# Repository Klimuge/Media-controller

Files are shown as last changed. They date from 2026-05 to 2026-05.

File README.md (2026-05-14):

# MediaController

Компактный портативный медиаконтроллер на ESP32-S3 с механическими кнопками и Bluetooth.

## Что это
Устройство подключается к телефону или компьютеру по Bluetooth или type-c кабелю и управляет медиа:
следующий/предыдущий трек, пауза, громкость, выводит название трека, автора, сколько трека прошло,
сколько осталось или сколько он длится. Что выводится на экране и что делает четвёртая кнопка можно настроить

## Железо
- ESP32-S3-WROOM-1-N16R8
- Cherry MX Red — механические кнопки
- EC11 — энкодер для громкости
- LCD 2004 + I2C — дисплей
- LiPo 3.7В 3000мАч аккумулятор
- TP4056 — зарядка
- AP2112K-3.3 — LDO, питание логики 3.3V
- MTS-123 — тумблер переключения режимов

## Что сделано
- Схема и PCB в KiCad
- BOM с футпринтами
- 3д модели корпуса
- План кода

## Программная часть (не реализована)

Система состоит из трёх компонентов.

### Прошивка ESP32

NimBLE-Arduino (h2zero) — устройство представляется системе как BLE HID-клавиатура
и отправляет медиакейкоды. ESP32-S3 работает как составное USB-устройство одновременно:
HID (медиаклавиатура) + CDC (виртуальный COM-порт для агента).
ArduinoJson парсит входящие JSON-сообщения от агента и обновляет LCD.
Тумблер MTS-123 переключает режимы, состояние читается через GPIO38/GPIO39 с INPUT_PULLDOWN.
Энкодер EC11 управляет громкостью через прерывания.

### Агент

Фоновое приложение в системном трее. Читает метаданные текущего трека, системное время и т. д,
отправляет их на устройство по USB Serial (JSON). Если кабель не подключён то по Bluetooth. Также должен запускать программу
если пользователь настроит запуск программы на кастомную (четвёртую) кнопку

### PC-конфигуратор

GUI-приложение (PySide6). Пользователь настраивает устройство через интерфейс,
конфигуратор рендерит Jinja2-шаблон прошивки с этими настройками и автоматически
прошивает устройство через arduino-cli / esptool. Фактически — настройка и перепрошивка
без написания кода.

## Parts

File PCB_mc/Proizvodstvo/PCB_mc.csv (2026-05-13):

Идентиф. | Обозначение | Посад. место | Количество | Значение | Поставщик и справка
1 | SW6 | MTS | 1 | MTS-123
2 | U3 | SOIC-8-1EP_3.9x4.9mm_P1.27mm_EP2.41x3.3mm_ThermalVias | 1 | TP4056-42-ESOP8
3 | U1 | ESP32-S3-WROOM-1 | 1 | ESP32-S3-WROOM-1
4 | SW5 | RotaryEncoder_Alps_EC11E-Switch_Vertical_H20mm_MountingHoles | 1 | RotaryEncoder_Switch_EC11
5 | SW4,SW3,SW2,SW1 | SW_Cherry_MX_1.00u_PCB | 4 | Cherry MX Red
6 | J1 | USB_C_Receptacle_GCT_USB4105-xx-A_16P_TopMnt_Horizontal | 1 | USB_C_Receptacle_USB2.0_14P
7 | C4,C5 | C_1206_3216Metric_Pad1.33x1.80mm_HandSolder | 2 | 1uF
8 | F1 | Fuse_1206_3216Metric_Pad1.42x1.75mm_HandSolder | 1 | 0.5А 13.2В
9 | C6,C7 | C_1206_3216Metric_Pad1.33x1.80mm_HandSolder | 2 | 10uF
10 | R8,R7 | R_1206_3216Metric_Pad1.30x1.75mm_HandSolder | 2 | 1k
11 | R6 | R_1206_3216Metric_Pad1.30x1.75mm_HandSolder | 1 | 1.2k
12 | SW7 | SW_PUSH-12mm_Wuerth-430476085716 | 1 | boot
13 | D2 | LED_1206_3216Metric_Pad1.42x1.75mm_HandSolder | 1 | Green
14 | R2,R1 | R_1206_3216Metric_Pad1.30x1.75mm_HandSolder | 2 | 5.1K
15 | R4,R5 | R_1206_3216Metric_Pad1.30x1.75mm_HandSolder | 2 | 10К
16 | SW8 | SW_PUSH-12mm_Wuerth-430476085716 | 1 | rst
17 | C2,C3 | C_1206_3216Metric_Pad1.33x1.80mm_HandSolder | 2 | 100nF
18 | D1 | LED_1206_3216Metric_Pad1.42x1.75mm_HandSolder | 1 | Red
19 | R3 | R_1206_3216Metric_Pad1.30x1.75mm_HandSolder | 1 | 0.4
20 | U2 | SOT-23-5 | 1 | AP2112K-3.3
21 | BT1 | AMASS_XT60-M_1x02_P7.20mm_Vertical | 1 | 3.7V 3Ah
22 | lcd1 | JST_XH_B4B-XH-A_1x04_P2.50mm_Vertical | 1 | 2004
23 | D3,D4 | D_SOD-123 | 2 | MBR0540

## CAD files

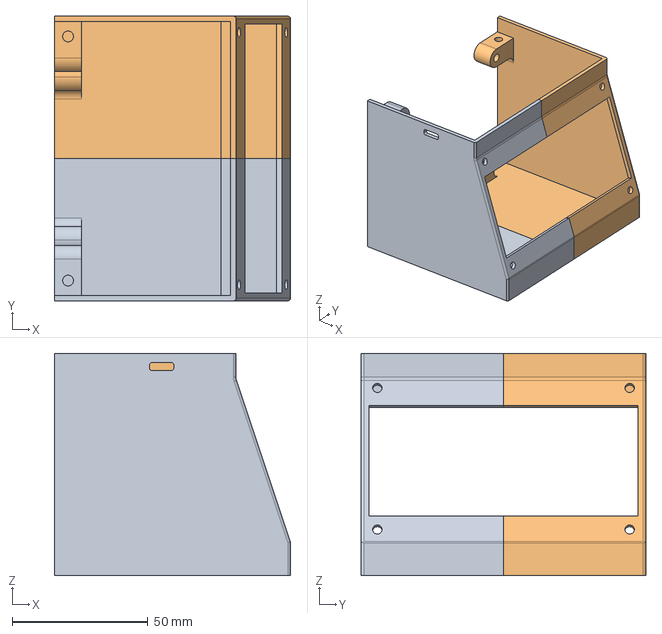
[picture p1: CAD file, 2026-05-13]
models/mc_base.step
87.0 x 105.0 x 82.0 mm

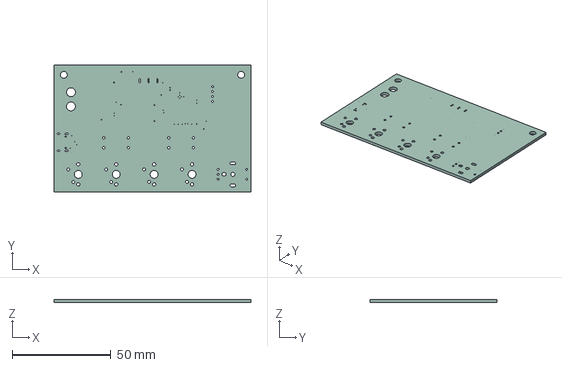
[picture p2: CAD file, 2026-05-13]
PCB_mc/PCB_mc.step
100.0 x 64.5 x 1.51 mm

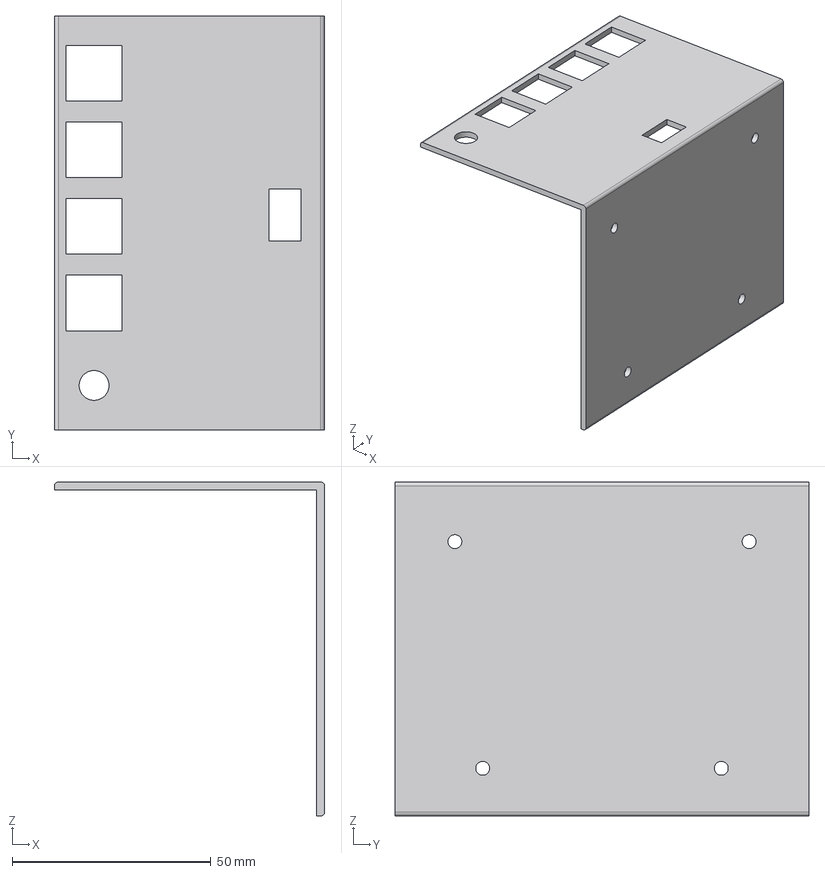
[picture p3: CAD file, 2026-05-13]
models/mc_cover.step
68.0 x 104.0 x 84.0 mm

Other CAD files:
models/mc_base.stl
models/mc_cover.stl

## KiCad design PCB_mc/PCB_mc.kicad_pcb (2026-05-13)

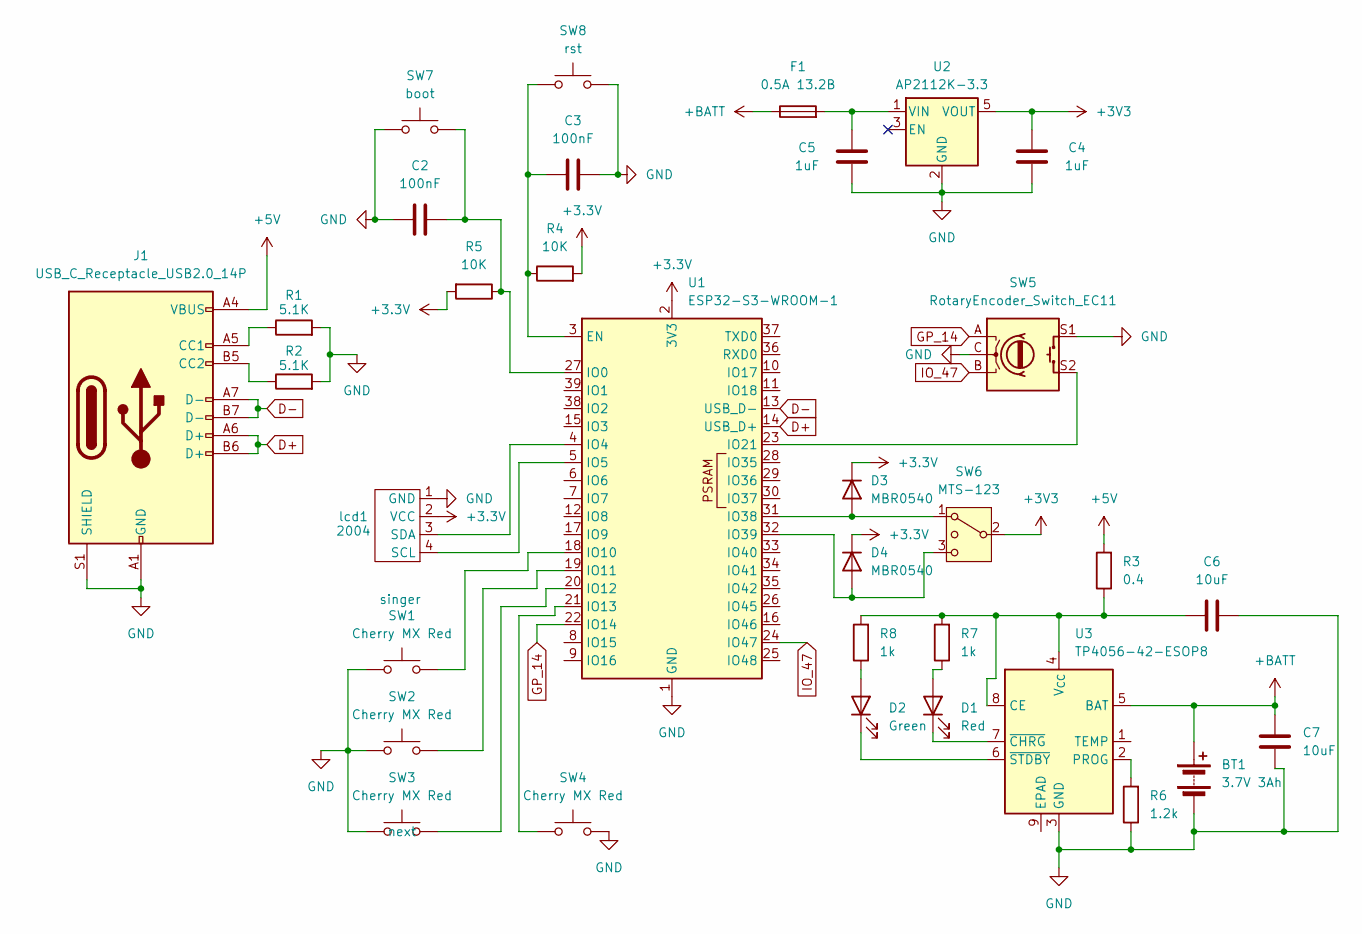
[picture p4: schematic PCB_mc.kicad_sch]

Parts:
BT1: 3.7V 3Ah; AMASS_XT60-M_1x02_P7.20mm_Vertical
C2, C3: 100nF; C_1206_3216Metric_Pad1.33x1.80mm_HandSolder
C4, C5: 1uF; C_1206_3216Metric_Pad1.33x1.80mm_HandSolder
C6, C7: 10uF; C_1206_3216Metric_Pad1.33x1.80mm_HandSolder
D1: Red; LED_1206_3216Metric_Pad1.42x1.75mm_HandSolder
D2: Green; LED_1206_3216Metric_Pad1.42x1.75mm_HandSolder
D3, D4: MBR0540; D_SOD-123
F1: 0.5А 13.2В; Fuse_1206_3216Metric_Pad1.42x1.75mm_HandSolder
J1: USB_C_Receptacle_USB2.0_14P; USB_C_Receptacle_GCT_USB4105-xx-A_16P_TopMnt_Horizontal
R1, R2: 5.1K; R_1206_3216Metric_Pad1.30x1.75mm_HandSolder
R3: 0.4; R_1206_3216Metric_Pad1.30x1.75mm_HandSolder
R4, R5: 10К; R_1206_3216Metric_Pad1.30x1.75mm_HandSolder
R6: 1.2k; R_1206_3216Metric_Pad1.30x1.75mm_HandSolder
R7, R8: 1k; R_1206_3216Metric_Pad1.30x1.75mm_HandSolder
SW1, SW2, SW3, SW4: Cherry MX Red; SW_Cherry_MX_1.00u_PCB
SW5: RotaryEncoder_Switch_EC11; RotaryEncoder_Alps_EC11E-Switch_Vertical_H20mm_MountingHoles
SW6: MTS-123; MTS
SW7: boot; SW_PUSH-12mm_Wuerth-430476085716
SW8: rst; SW_PUSH-12mm_Wuerth-430476085716
U1: ESP32-S3-WROOM-1
U2: AP2112K-3.3; SOT-23-5
U3: TP4056-42-ESOP8; SOIC-8-1EP_3.9x4.9mm_P1.27mm_EP2.41x3.3mm_ThermalVias
lcd1: 2004; JST_XH_B4B-XH-A_1x04_P2.50mm_Vertical

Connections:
+3.3V: D3.1 (K), D4.1 (K), R4.2, R5.2, U1.2 (3V3), lcd1.2 (VCC)
+3V3: C4.2, SW6.2 (3), U2.5 (VOUT)
+5V: J1.A4 (VBUS), J1.A9 (VBUS), J1.B4 (VBUS), J1.B9 (VBUS), R3.2
+BATT: BT1.1 (+), C7.1, F1.1, U3.5 (BAT)
D+: J1.A6 (D+), J1.B6 (D+), U1.14 (USB_D+)
D-: J1.A7 (D-), J1.B7 (D-), U1.13 (USB_D-)
GND: BT1.2 (-), C2.1, C3.1, C4.1, C5.1, C6.1, C7.2, J1.A1 (GND), J1.A12 (GND), J1.B1 (GND), J1.B12 (GND), J1.S1 (SHIELD), R1.2, R2.2, R6.1, SW1.1, SW2.1, SW3.1, SW4.2, SW5.C, SW5.S1, SW7.1, SW8.1, U1.1 (GND), U1.40 (GND), U1.41 (GND), U2.2 (GND), U3.3 (GND), lcd1.1 (GND)
GP_14: SW5.A, U1.22 (IO14)
IO_47: SW5.B, U1.24 (IO47)
unnamed: D1.2 (A), R7.1
unnamed: D1.1 (K), U3.7 (~CHRG)
unnamed: D2.2 (A), R8.1
unnamed: D2.1 (K), U3.6 (~STDBY)
unnamed: D3.2 (A), SW6.1, U1.31 (IO38)
unnamed: D4.2 (A), SW6.3 (4), U1.32 (IO39)
unnamed: J1.A5 (CC1), R1.1
unnamed: J1.B5 (CC2), R2.1
unnamed: C3.2, R4.1, SW8.2, U1.3 (EN)
unnamed: C2.2, R5.1, SW7.2, U1.27 (IO0)
unnamed: U1.4 (IO4), lcd1.3 (SDA)
unnamed: U1.5 (IO5), lcd1.4 (SCL)
unnamed: SW1.2, U1.18 (IO10)
unnamed: SW2.2, U1.19 (IO11)
unnamed: SW3.2, U1.20 (IO12)
unnamed: SW4.1, U1.21 (IO13)
unnamed: SW5.S2, U1.23 (IO21)
unnamed: C5.2, F1.2, U2.1 (VIN)
unnamed: C6.2, R3.1, R7.2, R8.2, U3.4 (V_{CC}), U3.8 (CE)
unnamed: R6.2, U3.2 (PROG)

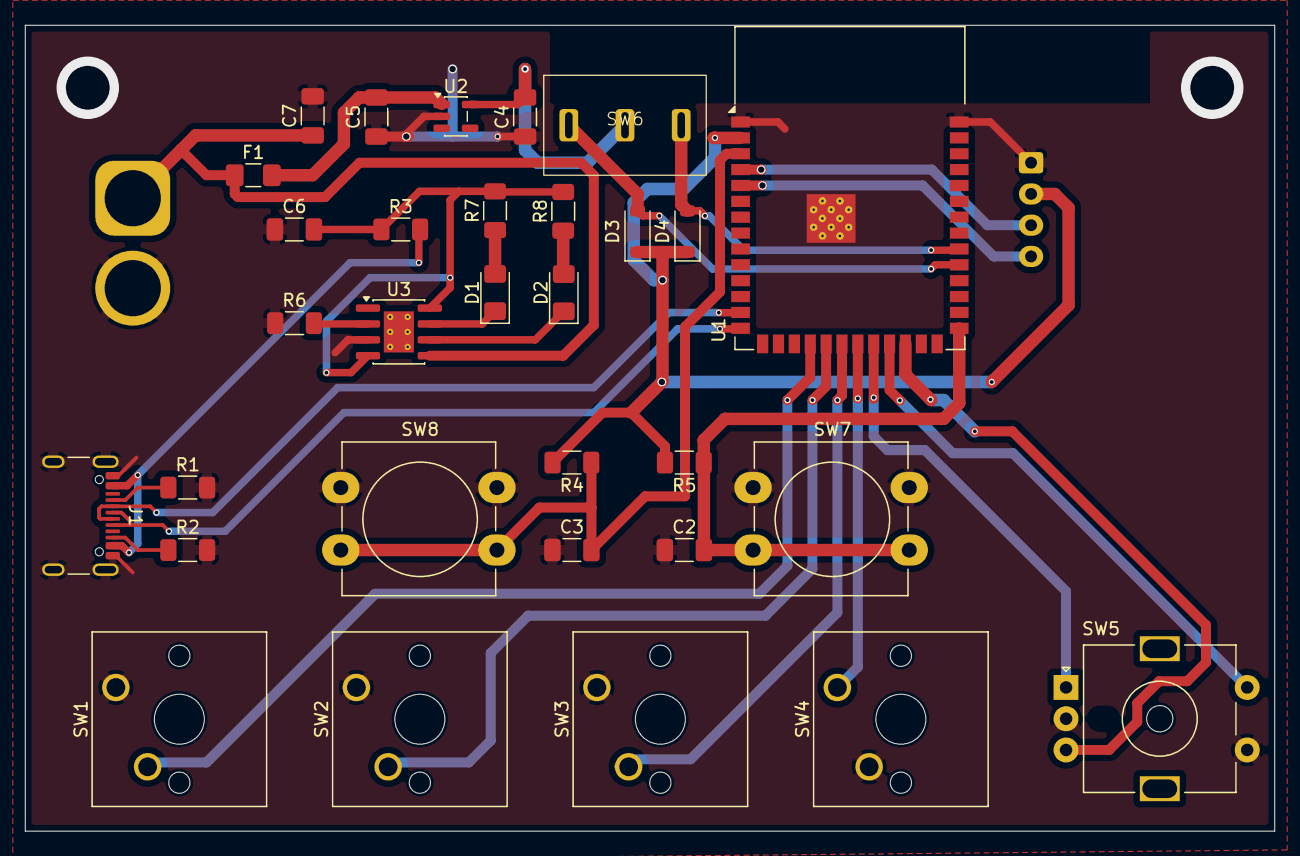
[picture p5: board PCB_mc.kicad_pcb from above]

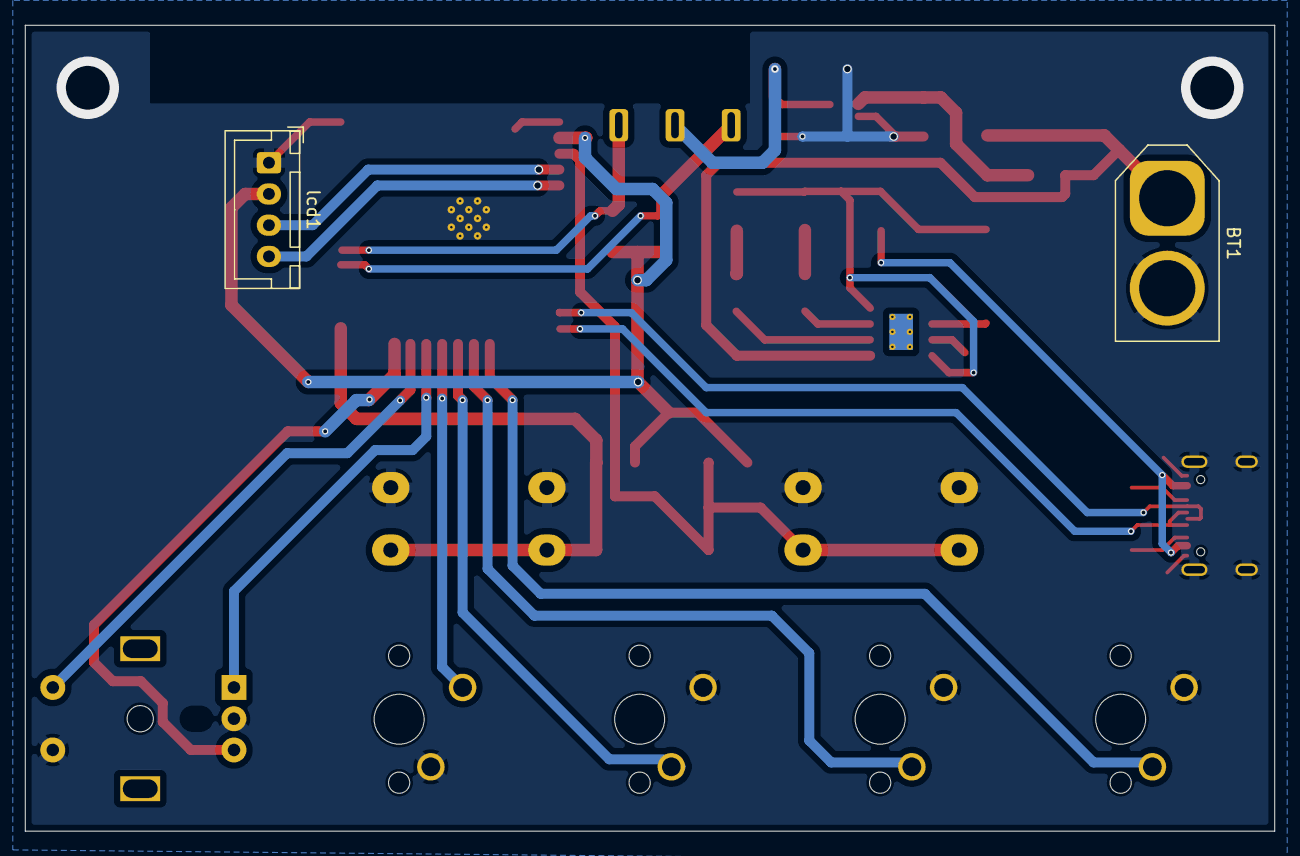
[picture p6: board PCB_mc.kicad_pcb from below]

Board: 2 copper layers, 100.0 x 64.5 mm, 33 parts (2 on the bottom side), 29 nets.
